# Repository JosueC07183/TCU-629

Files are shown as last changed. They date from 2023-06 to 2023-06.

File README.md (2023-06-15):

# TCU-629 Dispensador de alcohol en gel

Como parte de requisito de graduación los estudiantes de la Universidad de Costa Rica deben realizar un trabajo comunal universitario, comúnmente abreviado como TCU. En esta ocasión, un grupo de estudiantes de varias carreras tomaron la decisión de construir un dispensador de alcohol en gel automático desde 0, es decir, pensaron en un diseño que se adaptará a los materiales que contaba el laboratorio de industrial, por lo que fue un gran reto debido a que se tuvo invertir mucho tiempo en el diseño de las piezas, ya que era necesario que éstas tuvieran el mayor detalle posible, donde muchas ocasiones el material de trabajo no se adaptaba a lo solicitado, pero gracias al desempeño, perseverancia y voluntad del equipo de trabajo en ayudar al Hogar de ancianos San Pedro  Claver fue posible crear el dispensador, que se sometió a período de prueba cumpliendo satisfactoriamente su trabajo.

--- 
# Creación del primer prototipo
- Al cabo de 3 meses de mucho trabajo por sesiones diarias durante el período de verano de 2022-2023, el equipo de trabajo logró construir el primer dispensador, o la prueba de concepto.

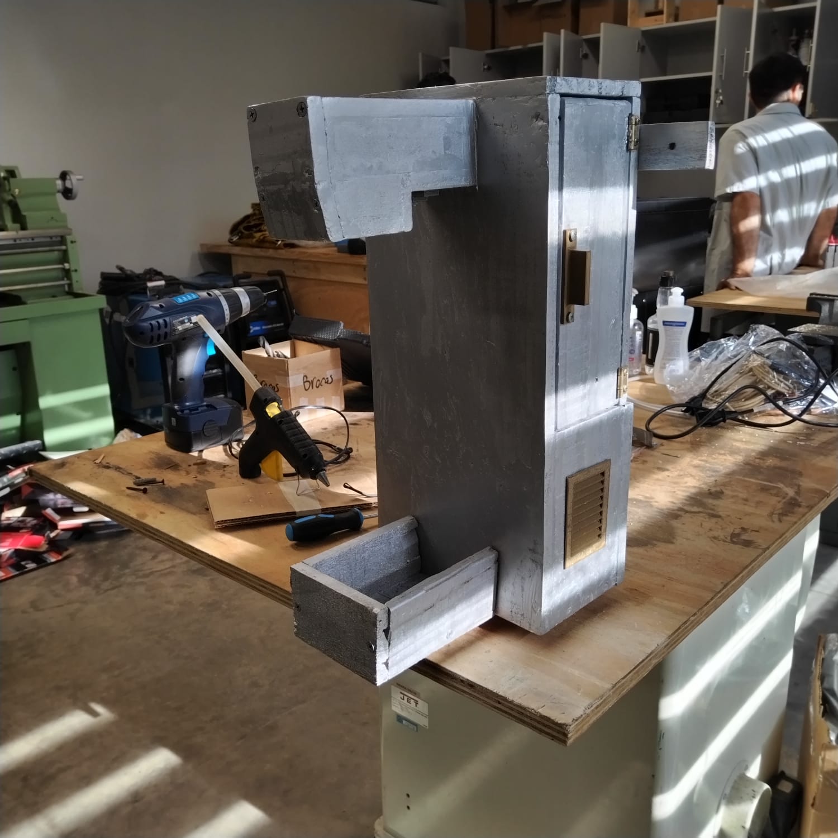
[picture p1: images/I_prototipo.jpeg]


**Nota**
> El dispensador mostrado en la imagen de arriba fue creado con los materiales disponibles en el laboratorio, que gracias a la creatividad del equipo de trabajo fue posible su construcción.

---
# Entrega del primer prototipo
- Una vez se completó el dispensador, se procedió a entregarlo al hogar de ancianos San Pedro Claver el día 20 de abril.

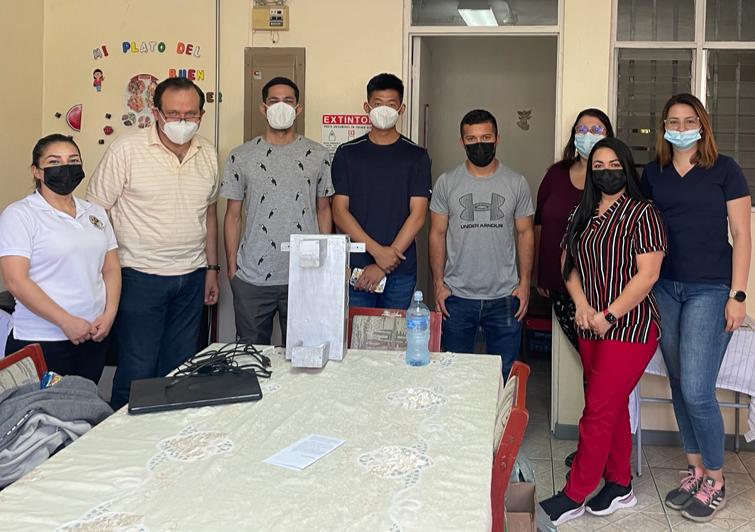
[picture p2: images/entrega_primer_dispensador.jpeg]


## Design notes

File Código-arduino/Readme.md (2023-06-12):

## En esta carpeta encontrará el código que le da vida a la estructura de nuestro dispensador.
---
- En el archivo .ino se muestra la documentación del código.

```
const int rele = 2;
int trig = 12;
int echo = 11;
float distancia;
long duracion;
int pot;
int cantidad;
int led_rojo = 5;
int led_verde= 6;
const int buzzer = 9;

void setup() {
  Serial.begin(9600);
  pinMode(rele , OUTPUT);
  pinMode(trig, OUTPUT);
  pinMode(echo, INPUT);
  pinMode(led_rojo, OUTPUT); 
  pinMode(led_verde, OUTPUT);
  pinMode(buzzer, OUTPUT);   
}
 
void loop(){

    pot = analogRead(A0);
    cantidad = pot/10.23;
    Serial.print("Cantidad es de = ");
    Serial.println(cantidad);

    digitalWrite(trig, LOW);
    delayMicroseconds(2);
    digitalWrite(trig, HIGH);
    delayMicroseconds(10);
    digitalWrite(trig, LOW);
    duracion = pulseIn(echo, HIGH);
    distancia = duracion/57.8;
    Serial.print(distancia);
    Serial.println("cm");

    digitalWrite(led_rojo, LOW);
    digitalWrite(led_verde, HIGH);
    
    //Código para el accionar de la bomba
    if(distancia <=12 && distancia>7){ 
    delay(500) ; 
    digitalWrite(rele, HIGH);
    digitalWrite(led_verde, LOW);
    digitalWrite(led_rojo, HIGH); 
    delay(cantidad);
    digitalWrite(rele, LOW);
    
    analogWrite (buzzer,5000); 
    delay(3000); 
    analogWrite (buzzer,0);
  	}

    //delay(100); // este delay es para reducir la cantidad de lecturas seguidas del sensor
  }  ```

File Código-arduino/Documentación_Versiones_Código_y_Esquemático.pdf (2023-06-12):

Universidad de Costa Rica

Escuela de Ingeniería Industrial
TCU-629 Dispensador Automatico, 2023 ´

# Documentación de Código y Esquema Electrónico

## Documentación de trabajo

### TCU-629-Ver1.0

Resumen

El presente documento muestra la documentación relacionada al circuito electrónico diseñado para el funcionamiento del dispensador, en este documento se presenta tanto el diagrama electrónico como la programación en Arduino para distintas propuestas que se han planteado implementar a lo largo del proceso de diseño del dispensador hasta la fecha, así como se indican las razones por las cuales algunas de las propuestas no fueron implementadas finalmente en el dispensador. También, se muestra la documentación relacionada a las versiones del circuito que si han sido implementadas en algún momento, así como la versión más reciente con la que se encuentra el dispensador funcionando.

### Fecha | Marzo, 2023 Autor 1 | Jose Pablo Valverde Brandford Profesor Coordinador | Michael Fernández Vega

1

TCU-629-Ver1.0 | Documentación de trabajo

# Índice

1. Versiones Propuestas. | 3

### 1.2. Versión con buzzer indicador de nivel de alcohol y LED indicador de accio-

2. Versión sin potenciómetro (06/01/2023). | 15
3. Versión Primer modelo (02/02/2023). | 17
4. Versión actual, segundo modelo (23/05/2023). | 20

2

TCU-629-Ver1.0 | Documentación de trabajo
1. Versiones Propuestas.
1.1. Versión con buzzer indicador de nivel de alcohol.

### Esta versión fue propuesta por el Autor 1, consiste en la implementación de un sistema

para controlar el nivel de alcohol en gel en el recipiente de almacenamiento, por medio de un sensor ultrasónico colocado en la boca del recipiente se mide la distancia desde la boca del recipiente a la capa superior del alcohol dentro del recipiente, en el momento en que el sensor mida una distancia definida como el fondo de la botella entonces el buzzer activa una alarma que indica que el recipiente se encuentra vacío.

### A continuación se enumeran las razones por las que no fue implementada esta versión:

### Dificultad para colocar el sensor en la boca de la botella y que a la vez se deje espacio

para realizar el llenado de la misma.

### Posibilidad de que la vida útil del sensor en la botella se reduzca debido a la humedad o al constante manejo y movimiento al que estaría expuesto debido a que por el diseño

del dispensador la botella debe sacarse del mismo para rellenarla.

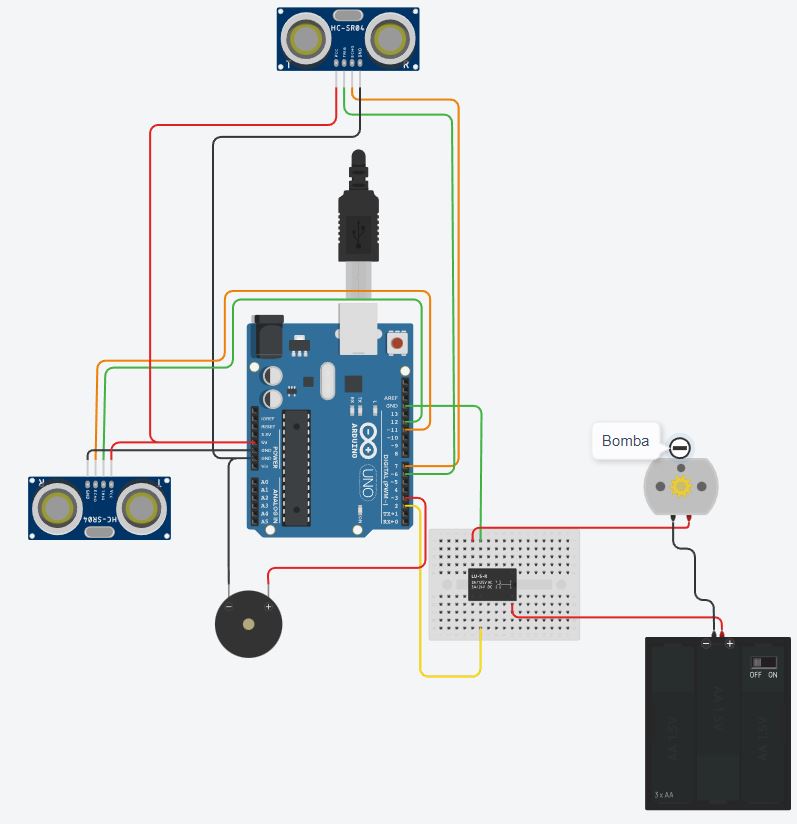
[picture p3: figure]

Figura 1: Captura del circuito con buzzer indicador de nivel de alcohol.

3

TCU-629-Ver1.0 | Documentación de trabajo

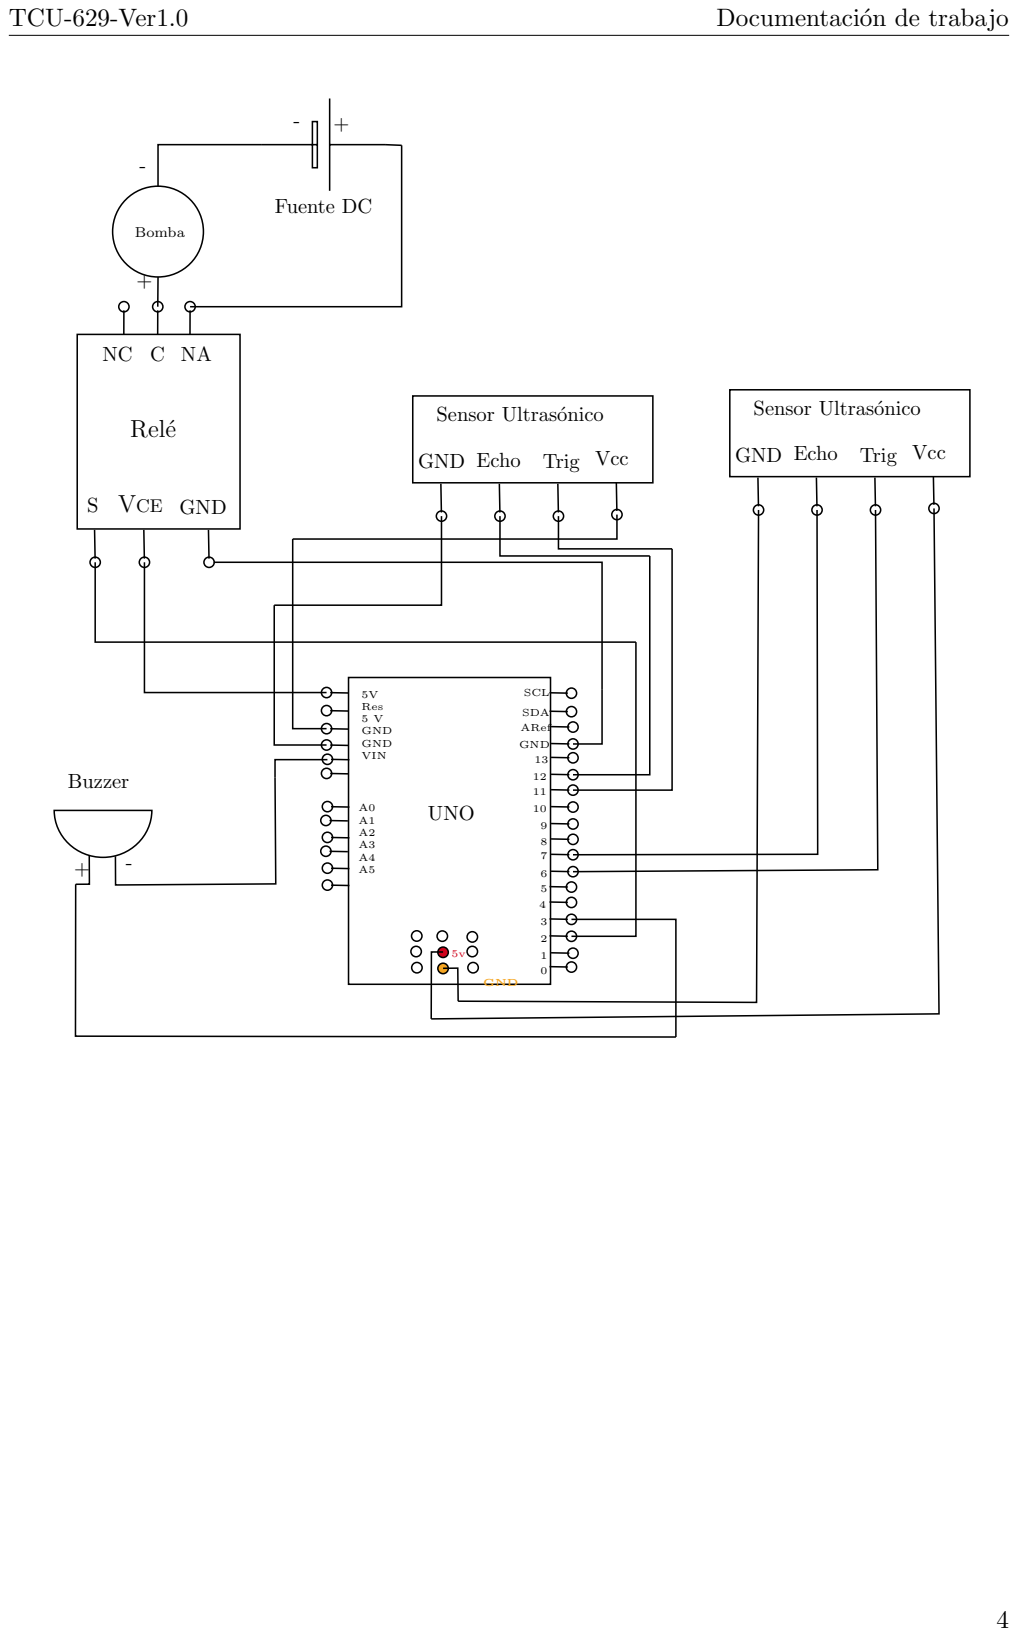
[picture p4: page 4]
UNO; 5V Res 5 V GND GND VIN; SCL; Bomba; S VCE GND; Relé; Fuente DC; GND Echo; Trig; Vcc; SDA; ARef; GND; Buzzer

Sensor Ultrasónico

TCU-629-Ver1.0 | Documentación de trabajo

1

2
3 #i n cl u d e <Wire . h>

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

12

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

19
20 v oid se tup ( ) {

21

22
23 | S e r ia l . b e gi n ( 9600 ) ; | // i n i c i a r pue r t o s e r i e
24 | pinMode (Bomba , OUTPUT) ; | // d e f i n i r pin como s a l i d a
25 | pinMode ( t r i g , OUTPUT) ;
26 | pinMode ( echo , INPUT PULLUP) ;

27
28 | pinMode ( t r i g 2 ,OUTPUT) ;
29 | pinMode ( echo 2 ,INPUT PULLUP) ;

30
31 pinMode ( buzzer ,OUTPUT) ;

32

33
34 }

35
36 v oid l o o p ( ) {

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

51

52
53 | }

54
55 //−+−+−+−+−+−+−+−+−+−+−+−+−+−+−+−+−+−+ Sen s o r mano y bomba +−+−+−+−+−+−+−+−+

5

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

65
66 i f ( d i s t a n c i a <=100 ) {

67
68 | d i g i t a lW r i t e (Bomba, HIGH) ;
69 | d el a y ( 1000 ) ; // Tiempo que dura l a bomba encendid a
70 | d i g i t a lW r i t e (Bomba, LOW) ;
71 | d el a y ( 5000 ) ;
72 | }
73 | e l s e {
74 | d i g i t a lW r i t e (Bomba, LOW) ;
75 | }

76
77 | d el a y ( 500 ) ;
78 | }

### Listing 1: Código de programación del circuito anterior

6

TCU-629-Ver1.0 | Documentación de trabajo

## 1.2. Versión con buzzer indicador de nivel de alcohol y LED indi-

cador de accionamiento de bomba.

Esta versión fue propuesta por el Autor 1, consiste en la implementación del mismo sistema para controlar el nivel de alcohol en gel en el recipiente de almacenamiento mencionado

### en la versión anterior pero ahora implementando también un diodo LED el cual indica el accionamiento de la bomba. La finalidad de la implementación del diodo LED es que en

caso de que el dispensador presente algún problema se pueda identificar rápidamente si el

### sistema de la bomba está alimentado y funcionando bien y descartar que el problema que

presente el dispensador sea propiciado por un fallo en las conexiones de l bomba o el sensor. En otras palabras, el LED sería un indicador de que el sistema electrónico del dispensador se encuentra funcionando correctamente.

### A continuación se enumeran las razones por las que no fue implementada esta versión:

### Dificultad para colocar el sensor en la boca de la botella y que a la vez se deje espacio

para realizar el llenado de la misma.

### Posibilidad de que la vida útil del sensor en la botella se reduzca debido a la humedad o al constante manejo y movimiento al que estaría expuesto debido a que por el diseño

del dispensador la botella debe sacarse del mismo para rellenarla.

### Se considera innecesario la implementación del LED ya que la bomba produce un sonido suficientemente alto como para que ese sonido pueda ser indicador de que el

sistema electrónico se encuentra funcionando correctamente.

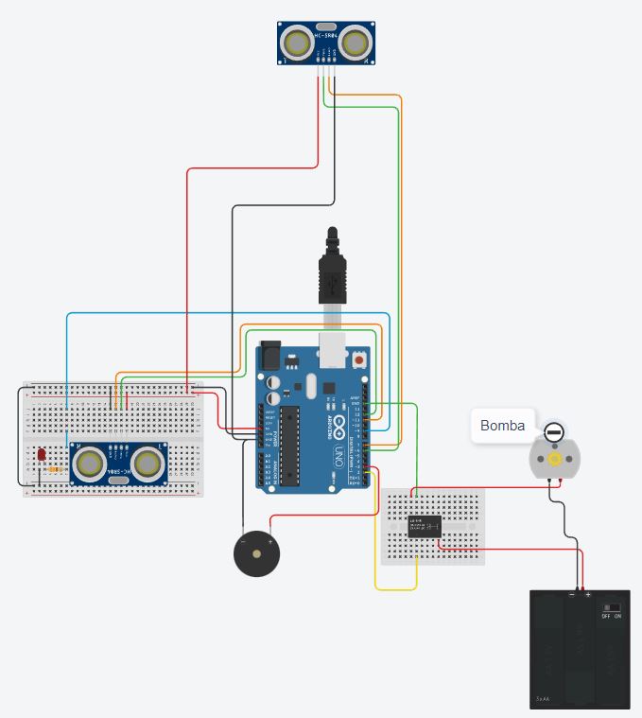
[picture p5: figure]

Figura 2: Captura del circuito con buzzer indicador de nivel de alcohol y LED indicador de accionamiento del dispensador.

7

TCU-629-Ver1.0 | Documentación de trabajo

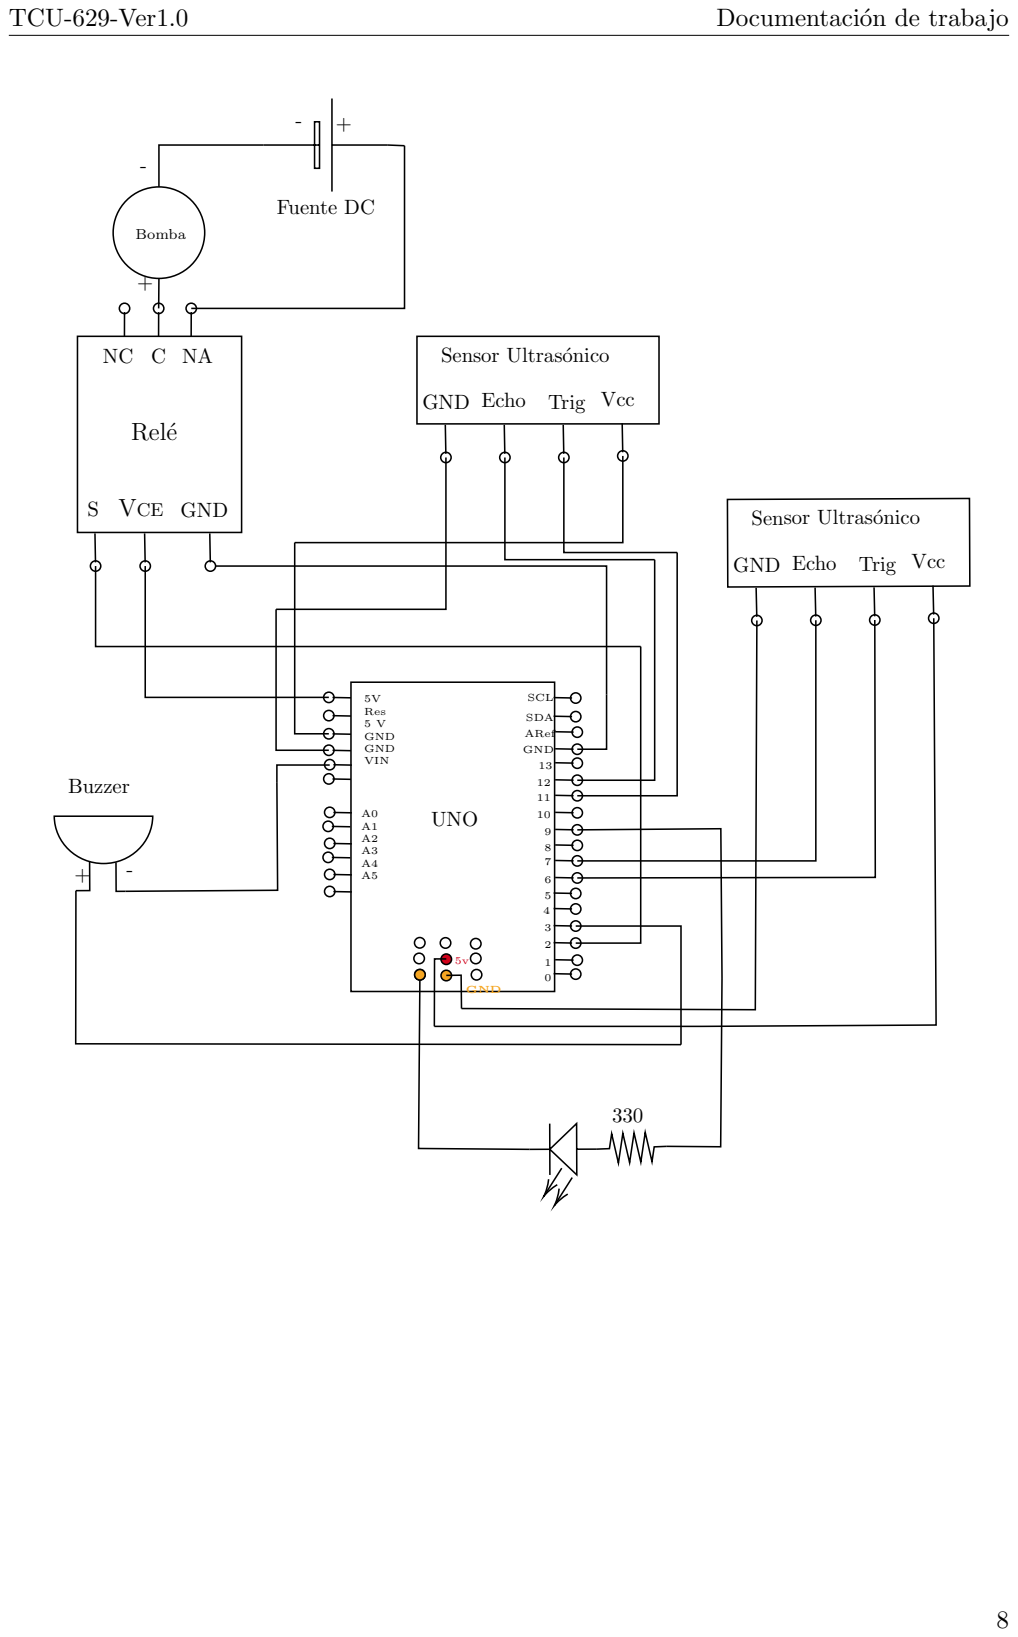
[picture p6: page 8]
UNO; 5V Res 5 V GND GND VIN; SCL; Bomba; S VCE GND; Relé; Fuente DC; GND Echo; Trig; Vcc; SDA; ARef; GND; Buzzer

Sensor Ultrasónico

TCU-629-Ver1.0 | Documentación de trabajo

1

2
3 #i n cl u d e <Wire . h>

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

19

20
21 v oid se tup ( ) {

22

23
24 | S e r ia l . b e gi n ( 9600 ) ; | // i n i c i a r pue r t o s e r i e
25 | pinMode (Bomba , OUTPUT) ; | // d e f i n i r pin como s a l i d a
26 | pinMode ( t r i g , OUTPUT) ;
27 | pinMode ( echo , INPUT PULLUP) ;
28 | pinMode (LED Bomba, OUTPUT) ;

29
30 | pinMode ( t r i g 2 ,OUTPUT) ;
31 | pinMode ( echo 2 ,INPUT PULLUP) ;

32
33 pinMode ( buzzer ,OUTPUT) ;

34

35
36 }

37
38 v oid l o o p ( ) {

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

53

54
55 | }

56

9

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

67
68 i f ( d i s t a n c i a <=100 ) {

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

80
81 | d el a y ( 500 ) ;
82 | }

### Listing 2: Código de programación del circuito anterior

10

TCU-629-Ver1.0 | Documentación de trabajo
1.3. Versión con Indicador de LEDs para nivel de alcohol.

### Esta versión fue propuesta por el Autor 1, consiste en la implementación de un sistema para controlar el nivel de alcohol en gel en el recipiente de almacenamiento por medio de

un indicador de tres niveles con LEDs, este sistema utiliza de igual forma que las versiones propuestas anteriores, un sensor ultrasónico para medir el nivel de alcohol en la botella,

### conforme el sensor colocado en la boca de la botella va midiendo una distancia mayor, el sistema indicador con LEDs va cambiando el LED alimentado, cuando la distancia medida

es pequeña, significa que la botella se encuentra relativamente llena, entonces el LED que se

### encuentra prendido es el verde, cuando la botella se encuentra en un rango medio entonces

el LED es amarillo, y cuando la botella se encuentra vacía entonces se prende el LED rojo.

### A continuación se enumeran las razones por las que no fue implementada esta versión:

### Dificultad para colocar el sensor en la boca de la botella y que a la vez se deje espacio

para realizar el llenado de la misma.

### Posibilidad de que la vida útil del sensor en la botella se reduzca debido a la humedad o al constante manejo y movimiento al que estaría expuesto debido a que por el diseño

del dispensador la botella debe sacarse del mismo para rellenarla.

### Se tendría que implementar el uso de una protoboard lo que implicaría un mayor

espacio dentro del dispensador para el circuito electrónico.

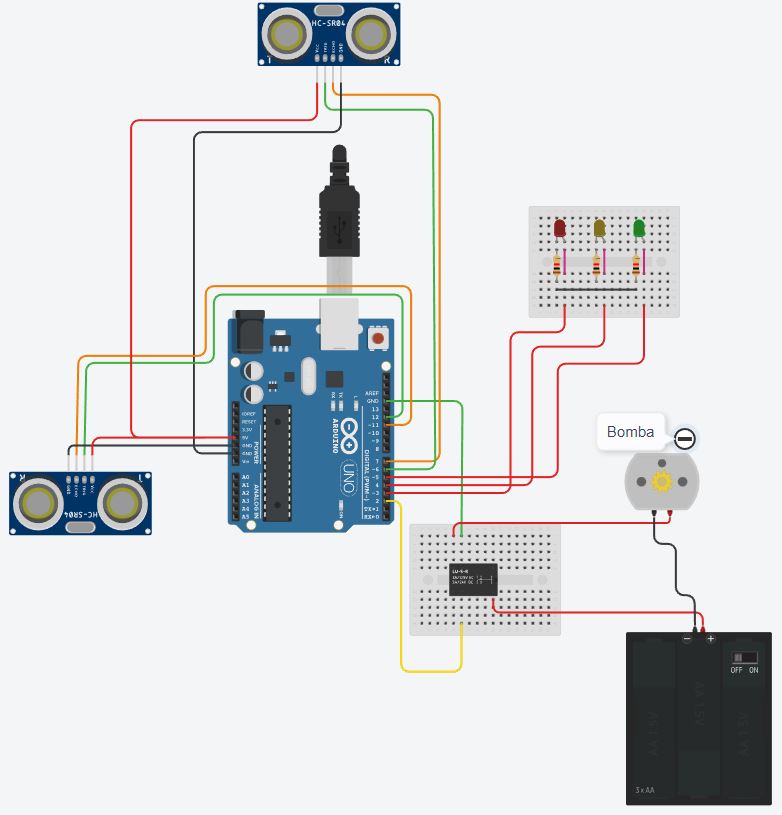
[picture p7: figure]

Figura 3: Captura del circuito con circuito de LEDs indicador de nivel de alcohol.

11

TCU-629-Ver1.0 | Documentación de trabajo

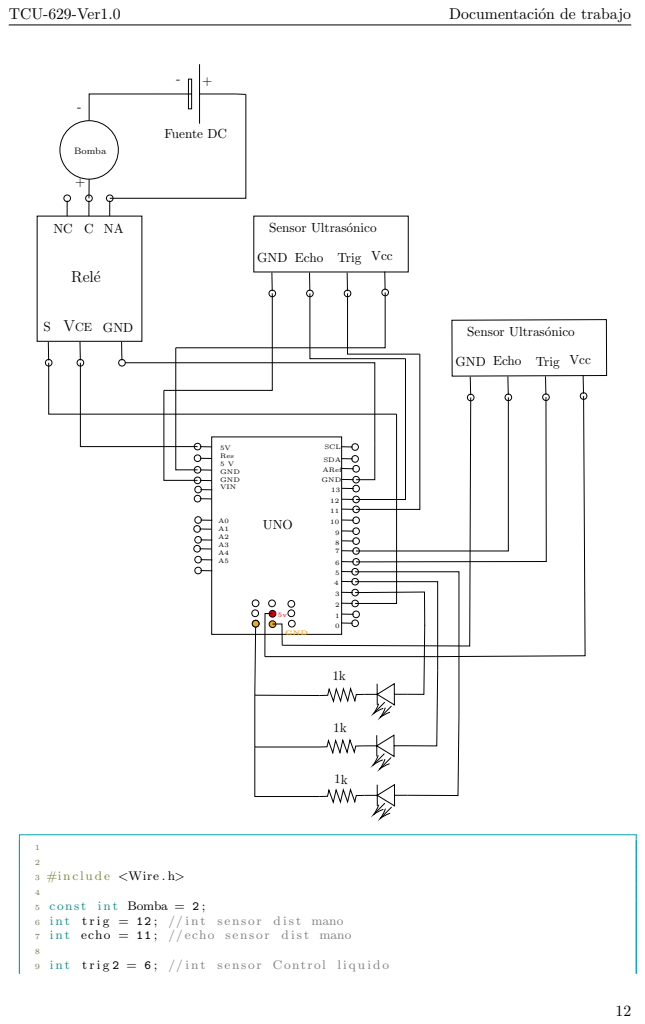
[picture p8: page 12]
UNO; 5V Res 5 V GND GND VIN; SCL; Bomba; S VCE GND; Relé; Fuente DC; GND Echo; Trig; Vcc; SDA; ARef; GND; 2 3 #i n cl u d e <Wire . h>; c o n s t i n t Bomba = 2 ;; i n t t r i g = 12 ; // i n t s e n s o r d i s t mano; i n t echo = 11 ; // echo s e n s o r d i s t mano

Sensor Ultrasónico

TCU-629-Ver1.0 | Documentación de trabajo
10 | i n t echo 2 = 7 ; // echo s e n s o r C on t r ol l i q u i d o

11

12

13

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

17
18 | i n t LED Ro jo Ind Nivel = 3 ;
19 | i n t LED Am a rill o Ind Ni vel = 4 ;
20 | i n t LED Verde Ind Nivel = 5 ;

21

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

25

26
27 v oid se tup ( ) {

28

29
30 | S e r ia l . b e gi n ( 9600 ) ; | // i n i c i a r pue r t o s e r i e
31 | pinMode (Bomba , OUTPUT) ; | // d e f i n i r pin como s a l i d a
32 | pinMode ( t r i g , OUTPUT) ;
33 | pinMode ( echo , INPUT PULLUP) ;

34

35
36 | pinMode ( t r i g 2 ,OUTPUT) ;
37 | pinMode ( echo 2 ,INPUT PULLUP) ;

38
39 | pinMode ( LED Ro jo Ind Nivel ,OUTPUT) ;
40 | pinMode ( LED Am a rill o Ind Nivel ,OUTPUT) ;
41 | pinMode ( LED Verde Ind Nivel ,OUTPUT) ;

42

43
44 }

45
46 v oid l o o p ( ) {

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

49

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

60
61 | d i g i t a lW r i t e ( LED Ro jo Ind Nivel ,HIGH) ;
62 | d i g i t a lW r i t e ( LED Am a rill o Ind Nivel ,LOW) ;
63 | d i g i t a lW r i t e ( LED Verde Ind Nivel ,LOW) ;

64

13

TCU-629-Ver1.0 | Documentación de trabajo
65 | }
66 | i f | ( Nivel<250 && Nivel>=100 ) {

67
68 | | d i g i t a lW r i t e ( LED Ro jo Ind Nivel ,LOW) ;
69 | | d i g i t a lW r i t e ( LED Am a rill o Ind Nivel ,HIGH) ;
70 | | d i g i t a lW r i t e ( LED Verde Ind Nivel ,LOW) ;

71
72 | }
73 | i f | ( Nivel<100 ) {

74
75 | | d i g i t a lW r i t e ( LED Ro jo Ind Nivel ,LOW) ;
76 | | d i g i t a lW r i t e ( LED Am a rill o Ind Nivel ,LOW) ;
77 | | d i g i t a lW r i t e ( LED Verde Ind Nivel ,HIGH) ;

78
79 | }

80

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

92
93 i f ( d i s t a n c i a <=100 ) {

94
95 | | d i g i t a lW r i t e (Bomba, HIGH) ;
96 | | d el a y ( 1000 ) ; // Tiempo que dura l a bomba encendid a
97 | | d i g i t a lW r i t e (Bomba, LOW) ;
98 | | d el a y ( 5000 ) ;
99 | }
100 | e l s e {
101 | d i g i t a lW r i t e (Bomba, LOW) ;
102 | }

103
104 | d el a y ( 500 ) ;
105 | }

### Listing 3: Código de programación del circuito anterior

14

TCU-629-Ver1.0 | Documentación de trabajo
2. Versión sin potenciómetro (06/01/2023).

Esta versión es la más básica para el funcionamiento del dispensador, fue propuesta por los compañeros que empezaron el diseño de este proyecto en semestres anteriores, consiste

únicamente en un sensor ultrasónico colocado en la boquilla del dispensador que detecta cuando se acerca la mano, luego es accionada la bomba de diafragma que toma el alcohol del dispensador presente dentro de la carcasa del dispensador y lo dispensa por medio de la boquilla a la mano del usuario, todo controlado por el módulo de Arduino UNO. Esta

versión fue implementada y probada con éxito en el dispensador.

15

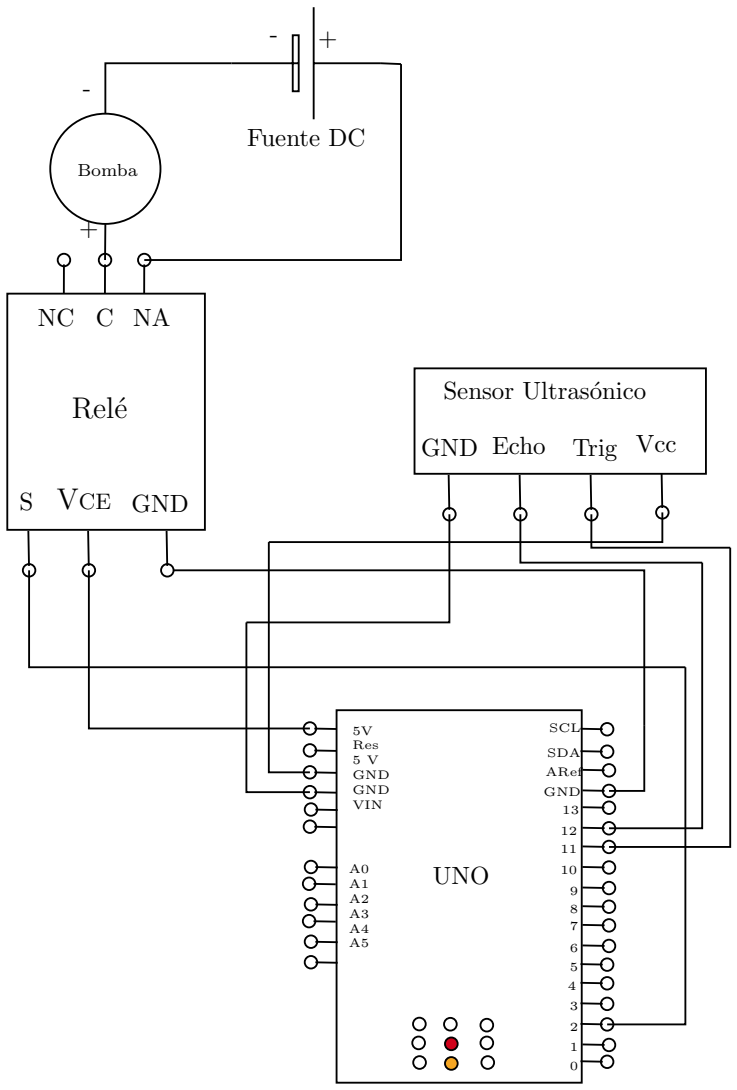
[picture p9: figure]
UNO; 5V Res 5 V GND GND VIN; SCL; Bomba; S VCE GND; Relé; Fuente DC; GND Echo; Trig; Sensor Ultrasónico; Vcc; SDA; ARef; GND

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

7
8 | v oid se tup ( ) {
9 | S e r ia l . b e gi n ( 9600 ) ; | // i n i c i a r pue r t o s e r i e
10 | pinMode ( r e l e , OUTPUT) ; | // d e f i n i r pin como s a l i d a
11 | pinMode ( t r i g , OUTPUT) ; | // t r i g s a l i d a
12 | pinMode ( echo , INPUT) ; // echo en t r ad a
13 | }

14
15 v oid l o o p ( ) {

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

39 }

### Listing 4: Código de programación del circuito anterior

16

TCU-629-Ver1.0 | Documentación de trabajo
3. Versión Primer modelo (02/02/2023).

### Esta versión se basa en la anterior, es en esencia exactamente igual electrónicamen-te hablando pero ahora por recomendación del profesor coordinado Michael Fernández se implementa un potenciómetro que permite regular la cantidad de alcohol que dispensa el

dispositivo diseñado. Esta versión fue implementada y probada con éxito en el dispensador y a la fecha de la última actualización del presente documento, esta es la versión con la que se encuentra funcionando el dispositivo.

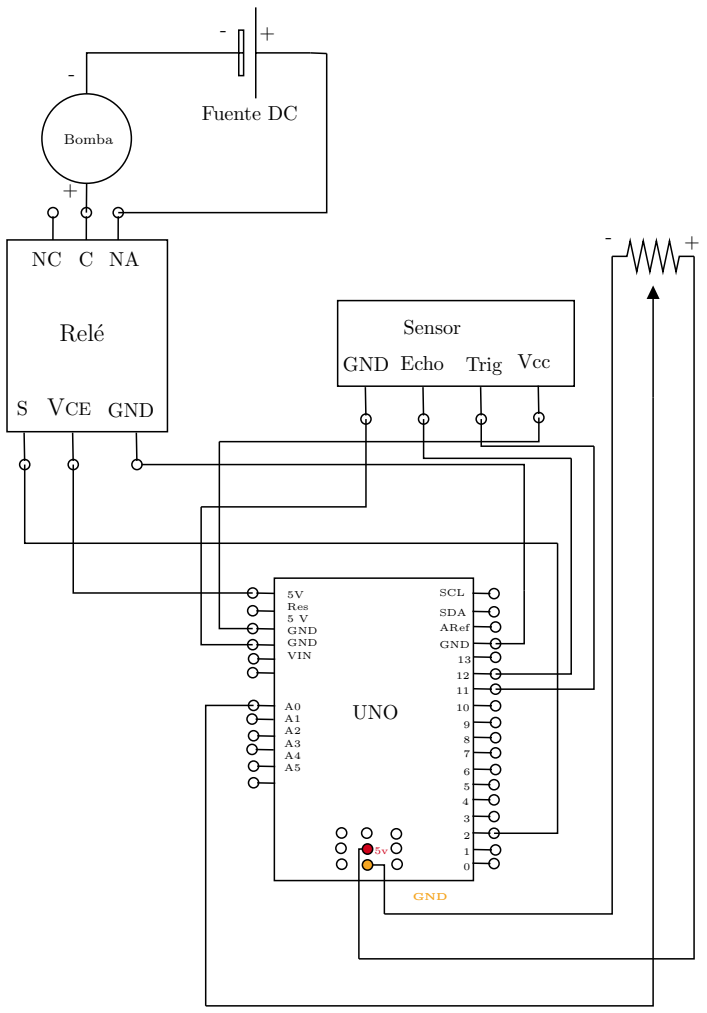
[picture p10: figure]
UNO; 5V Res 5 V GND GND VIN; SCL; Bomba; S VCE GND; Relé; Fuente DC; GND; GND Echo; Trig; Sensor; Vcc; SDA; ARef

Figura 4: Esquemático eléctrico dispensador de alcohol.

17

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

9

10
11 | v oid se tup ( ) {
12 | S e r ia l . b e gi n ( 9600 ) ; | // i n i c i a r pue r t o s e r i e
13 | pinMode ( r e l e , OUTPUT) ; | // d e f i n i r pin como s a l i d a
14 | pinMode ( t r i g , OUTPUT) ; // t r i g s a l i d a
15 | pinMode ( echo , INPUT) ; // echo en t r ad a
16 | }

17
18 v oid l o o p ( ) {

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

36

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

18

TCU-629-Ver1.0 | Documentación de trabajo

### Listing 5: Código de programación del pimer modelo

19

TCU-629-Ver1.0 | Documentación de trabajo
4. Versión actual, segundo modelo (23/05/2023).

### A partir de la retroalimentación obtenida a partir del personal del hogar de ancianos

luego del periodo de pruebas del primer modelo del dispensador, se evalúan varias opciones

### de mejora, escogiendo la opción de implementar un sistema indicador de LEDs y buzzer

con el fin de que sirva como señal al usuario para que éste sepa cuando el dispensador se encuentra listo para dispensar el alcohol, y cuando el dispositivo se encuentra realizando el

### delay entre accionamiento, esto permite evitar que el usuario ponga la mano muy seguido y

al dispensador no le dé tiempo de dispensar el alcohol.

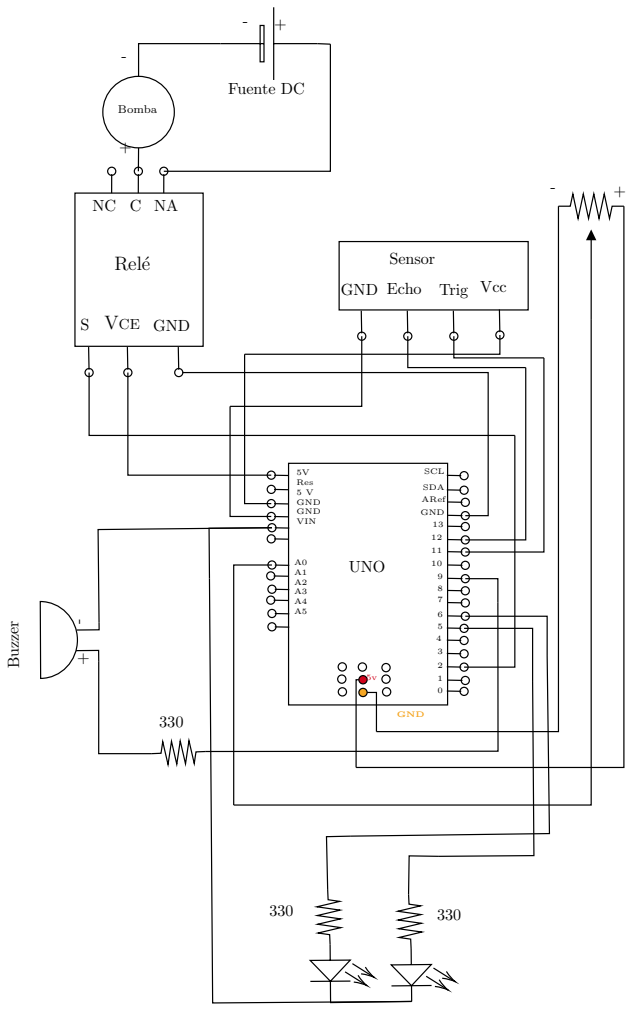
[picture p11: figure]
UNO; 5V Res 5 V GND GND VIN; SCL; Bomba; S VCE GND; Relé; Fuente DC; GND; GND Echo; Trig; Sensor; Vcc; SDA; ARef; Buzzer

Figura 5: Esquemático eléctrico dispensador de alcohol.

20

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

12
13 | v oid se tup ( ) {
14 | S e r ia l . b e gi n ( 9600 ) ; | // i n i c i a r pue r t o s e r i e
15 | pinMode ( r e l e , OUTPUT) ; | // d e f i n i r pin como s a l i d a
16 | pinMode ( t r i g , OUTPUT) ; // t r i g s a l i d a
17 | pinMode ( echo , INPUT) ; // echo en t r ad a
18 | pinMode ( l e d r o j o , OUTPUT) ;
19 | pinMode ( l e d v e r d e , OUTPUT) ;
20 | pinMode ( buzzer , OUTPUT) ;
21 | }

22
23 v oid l o o p ( ) {

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

21

TCU-629-Ver1.0 | Documentación de trabajo

53
54 | an al o gW ri te ( buzzer , 5000 ) ;
55 | d el a y ( 3000 ) ; // demora para que vuel v a a f u n ci o n a r l a bomba en c a s o
| de u t i l i z a r s e s e g ui d o
56 | an al o gW ri te ( buzzer , 0 ) ;
57 | }

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

### Listing 6: Código de programación más reciente a la fecha

22

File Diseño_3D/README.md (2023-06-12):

## En esta carpeta se encontrará el archivo del diseño 3D del dispensador de alcohol.

---

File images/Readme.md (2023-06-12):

# Evidencias de trabajo
---
- En esta carpeta contiene las imágenes de los momentos más importantes del proyecto.

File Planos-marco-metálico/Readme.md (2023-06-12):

# Dimensiones del marco metálico
---
> Aquí encontrará un archivo pdf que contiene las dimensiones del esqueleto del dispositivo, las podrá consultar para conocer con más detalles del trabajo.

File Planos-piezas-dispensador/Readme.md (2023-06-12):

# Dimensiones y enumeraciones de las piezas
---
> En este archivo pdf podrá consultar el armado del dispensador, ubicación de las piezas, cortes y dimensiones.

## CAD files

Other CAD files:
Planos-piezas-dispensador/Planos segundo modelo.dwg
Diseño_3D/Piezas Impresión 3D/Base Sensor Hueco 2.0 v6 v7 v2.f3d
Diseño_3D/Piezas Impresión 3D/BoquillaConica v2.f3d
Diseño_3D/Piezas Impresión 3D/Manilla v2.f3d
Diseño_3D/Piezas Impresión 3D/Rejilla v3 v2.f3d
Diseño_3D/Piezas Impresión 3D/Soporte Manguera v4 v2.f3d
Diseño_3D/Piezas Impresión 3D/Soporte_Poten v4.f3d
Diseño_3D/Piezas Impresión 3D/bocaadaptador v4 v1.f3d

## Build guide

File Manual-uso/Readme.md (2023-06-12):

# Manual de uso
> Aquí podrá encontrar un archivo (a modo de resumen) del uso del dispositivo.

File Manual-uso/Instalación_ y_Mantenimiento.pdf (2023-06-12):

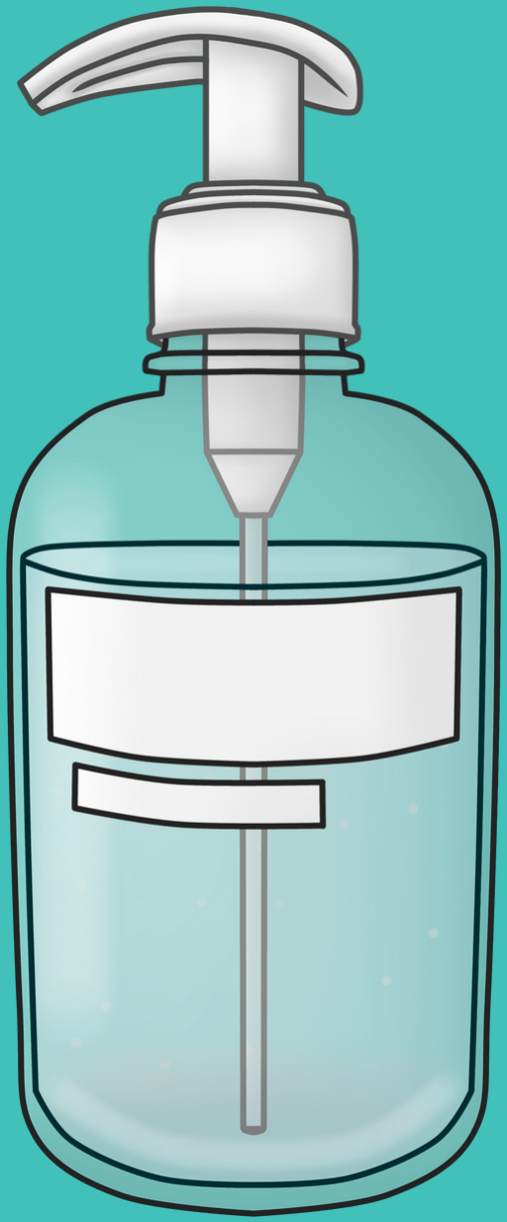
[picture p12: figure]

# INSTALACION Y MANTNIMIENTO DEL DISPENSADOR DE ALCOHOL

# Instrucciones Para

## TCU-629-G08

# Instrucciones de Instalacion

# Diagrama de flujo de Instalacion

# Instrucciones de Mantenimiento

# Diagrama de Flujo de Mantenimiento

01

02

03

04

# CONTENIDOS

# INSTALACION DEL DISPENSADOR

Definir un lugar seguro cerca de alguna fuente de alimentacion, para colocar el dispensador.

01

Realice los agujeros nesesarios en la 02 pared donde se ubica el dispositivo.

Con la ayuda de tacos tarugos de 1/8 sujete el dispositvo a la pared y conecte a la fuente de alimentacion.

03

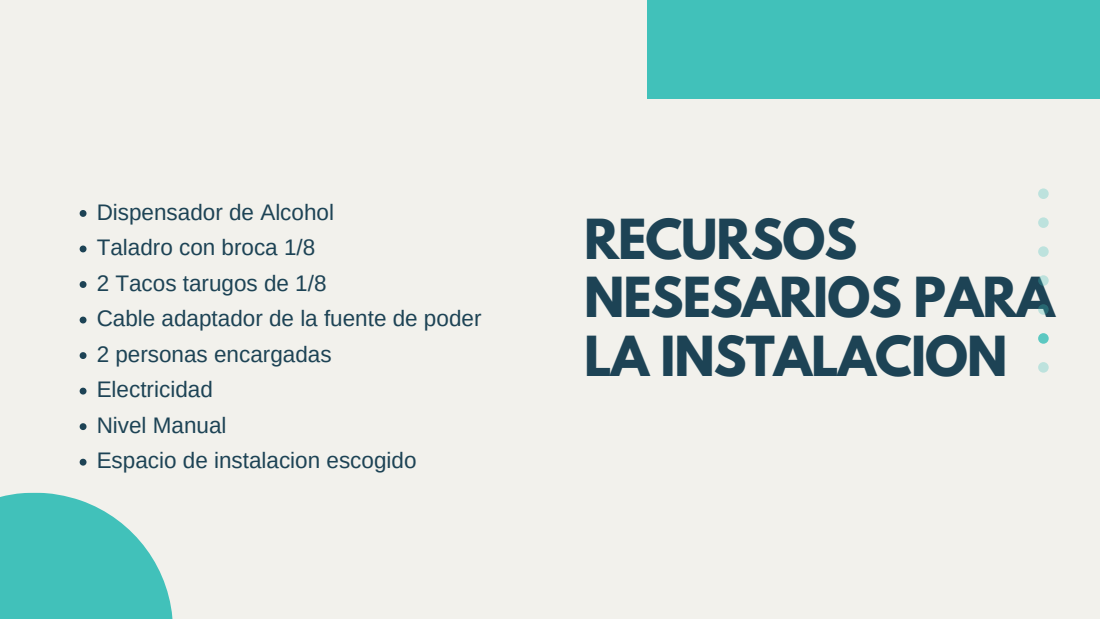
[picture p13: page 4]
RECURSOS NESESARIOS PARA LA INSTALACION

Dispensador de Alcohol
Taladro con broca 1/8
2 Tacos tarugos de 1/8
Cable adaptador de la fuente de poder
2 personas encargadas
Electricidad
Nivel Manual
Espacio de instalacion escogido

# DIAGRAMA DE FLUJO INSTALACION

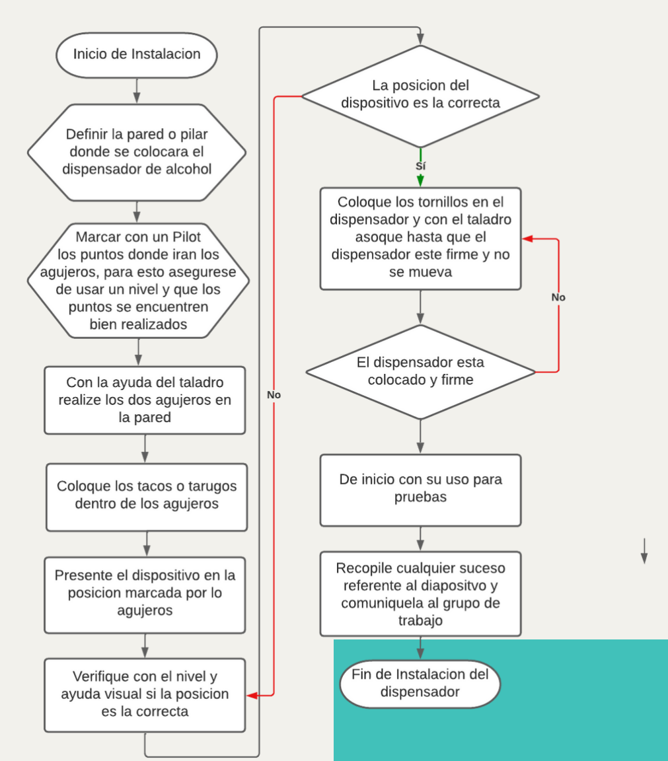
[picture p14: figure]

Se realiza mantenimiento cada vez que se agote el alchol en gel del dispensador, para ello desconecte el mismo.

01

Al prototipo tener su propia botella esta debe ser retirada, con cuidado de no dañar la manguera de dispensado.

02

Rellene la misma botella e introdusca de nuevo en el
dispositvo, coloque la tapa y cierre el dispensador.

03

# MANTENIMIENTO DEL DISPENSADOR

# RECURSOS DE MANTENIEMTO

## Alcohol en gel 500 ml Botella del dispensador tapa de la botella 1 persona encargada

# DIAGRAMA DE FLUJO DE MANTENIMIENTO

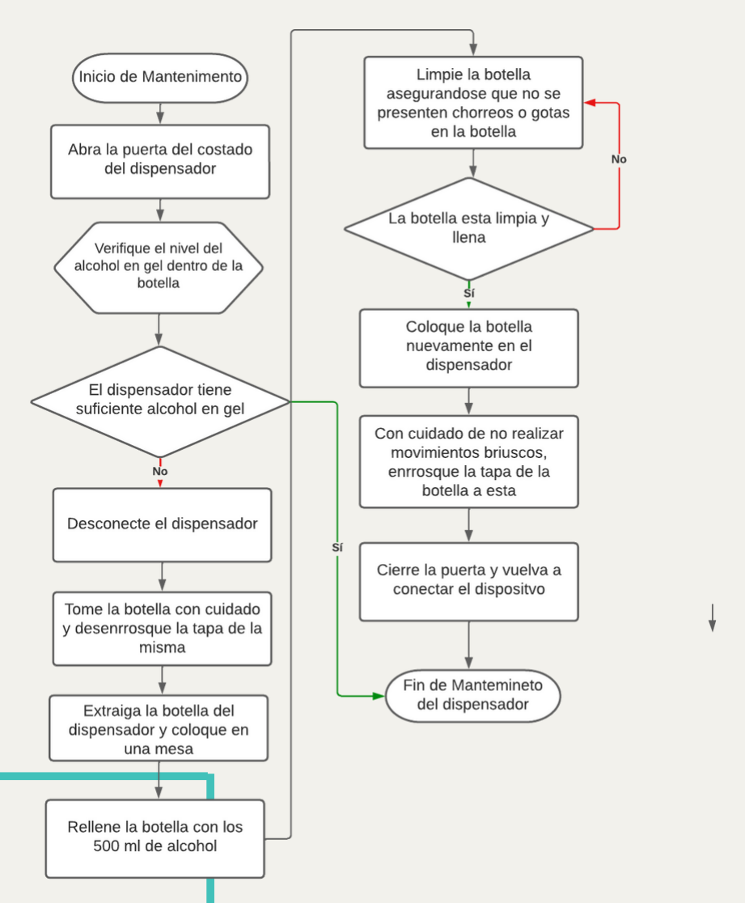
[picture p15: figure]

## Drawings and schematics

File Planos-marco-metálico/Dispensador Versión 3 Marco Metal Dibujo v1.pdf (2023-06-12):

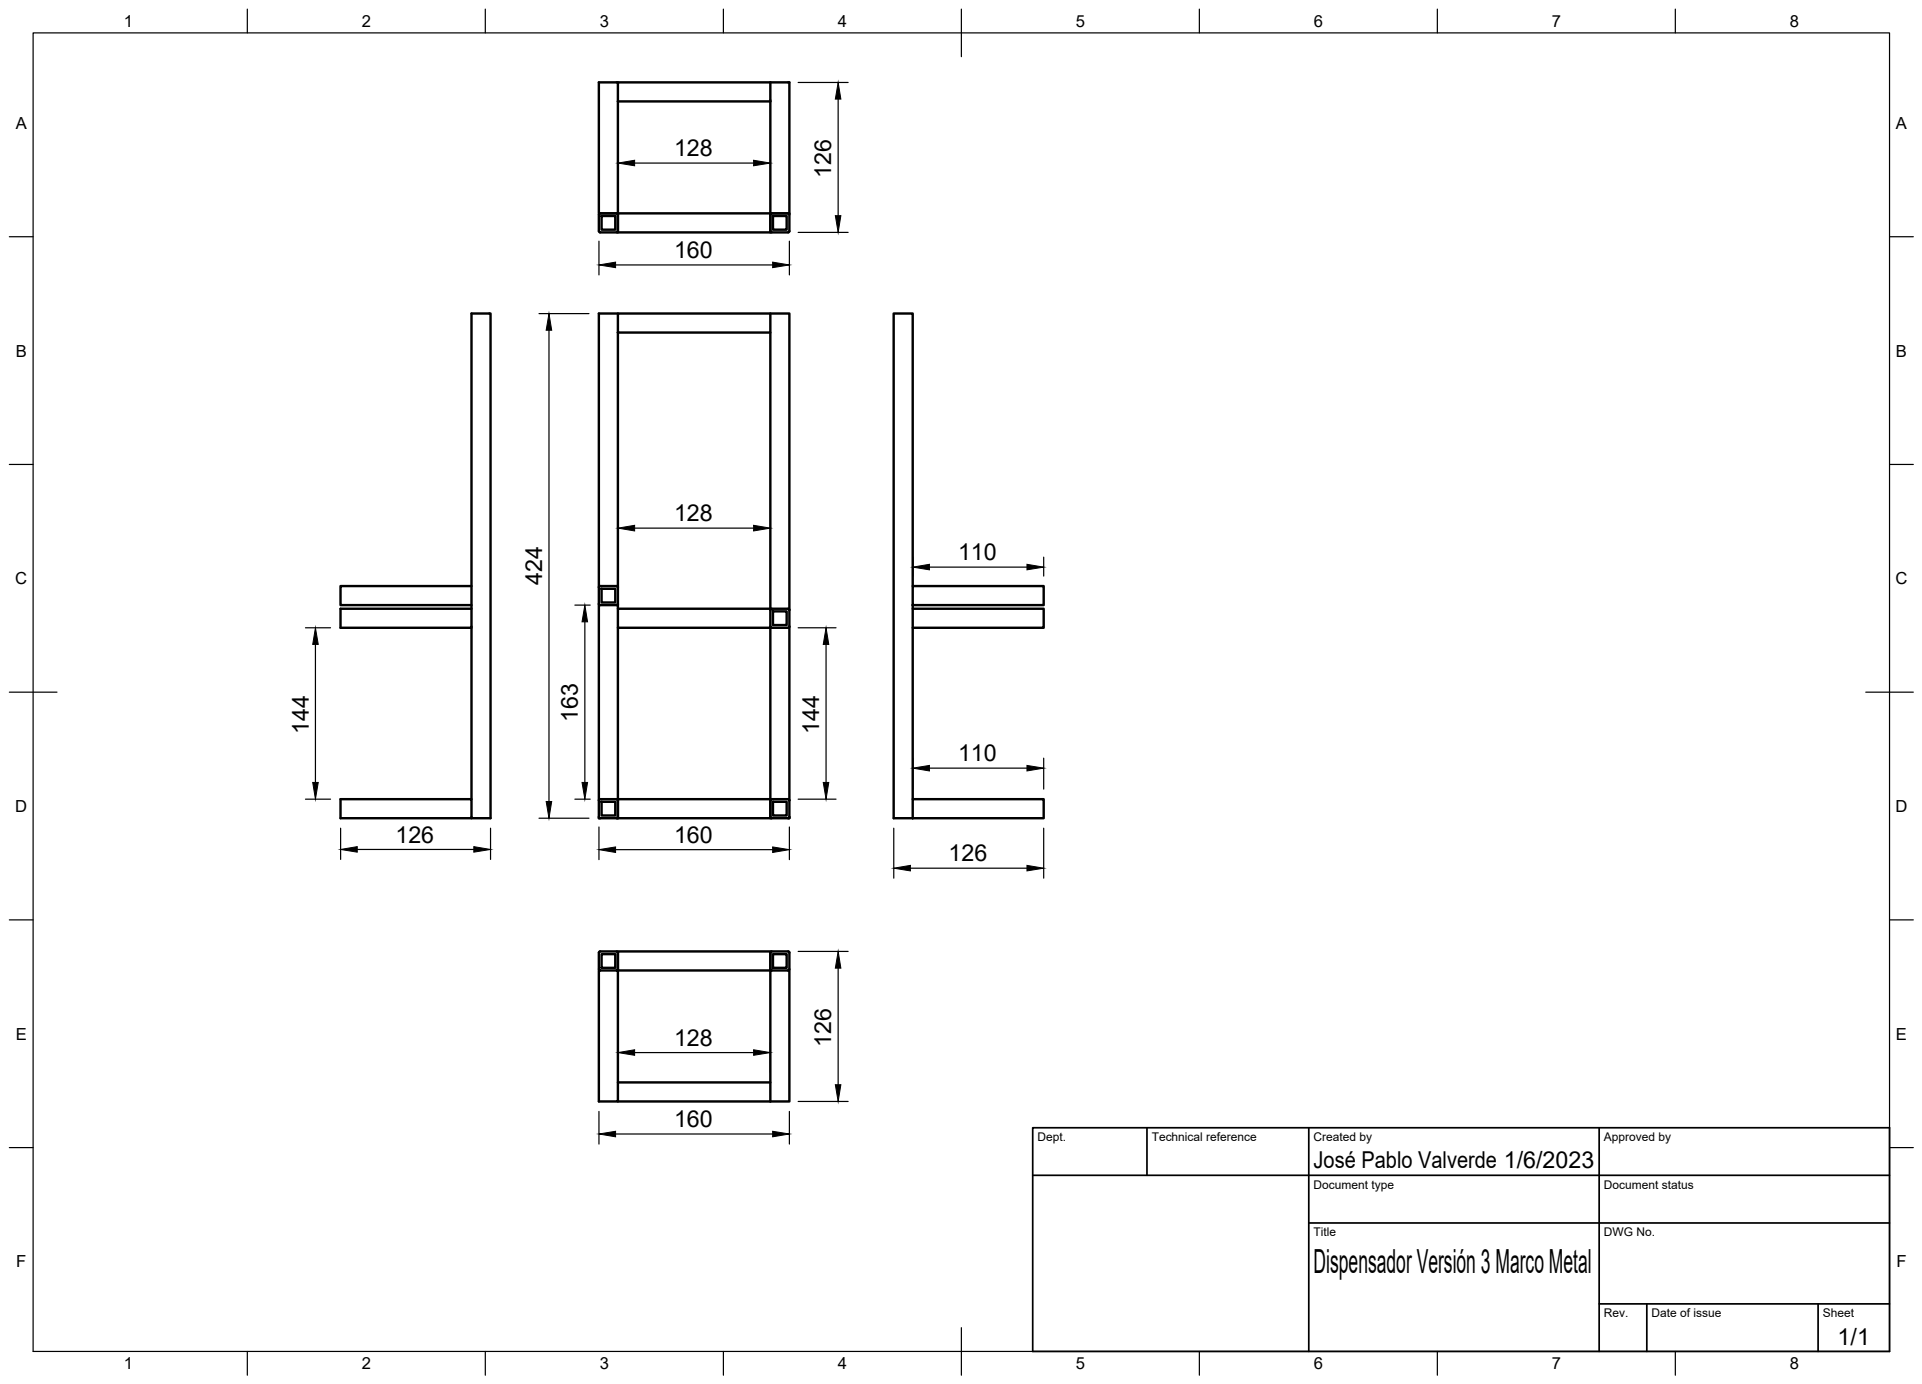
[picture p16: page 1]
Title; DWG No.; Rev.; Date of issue; Sheet

Dept. | Technical reference | Created by José Pablo Valverde 1/6/2023 | Approved by

Document type | Document status

Dispensador Versión 3 Marco Metal

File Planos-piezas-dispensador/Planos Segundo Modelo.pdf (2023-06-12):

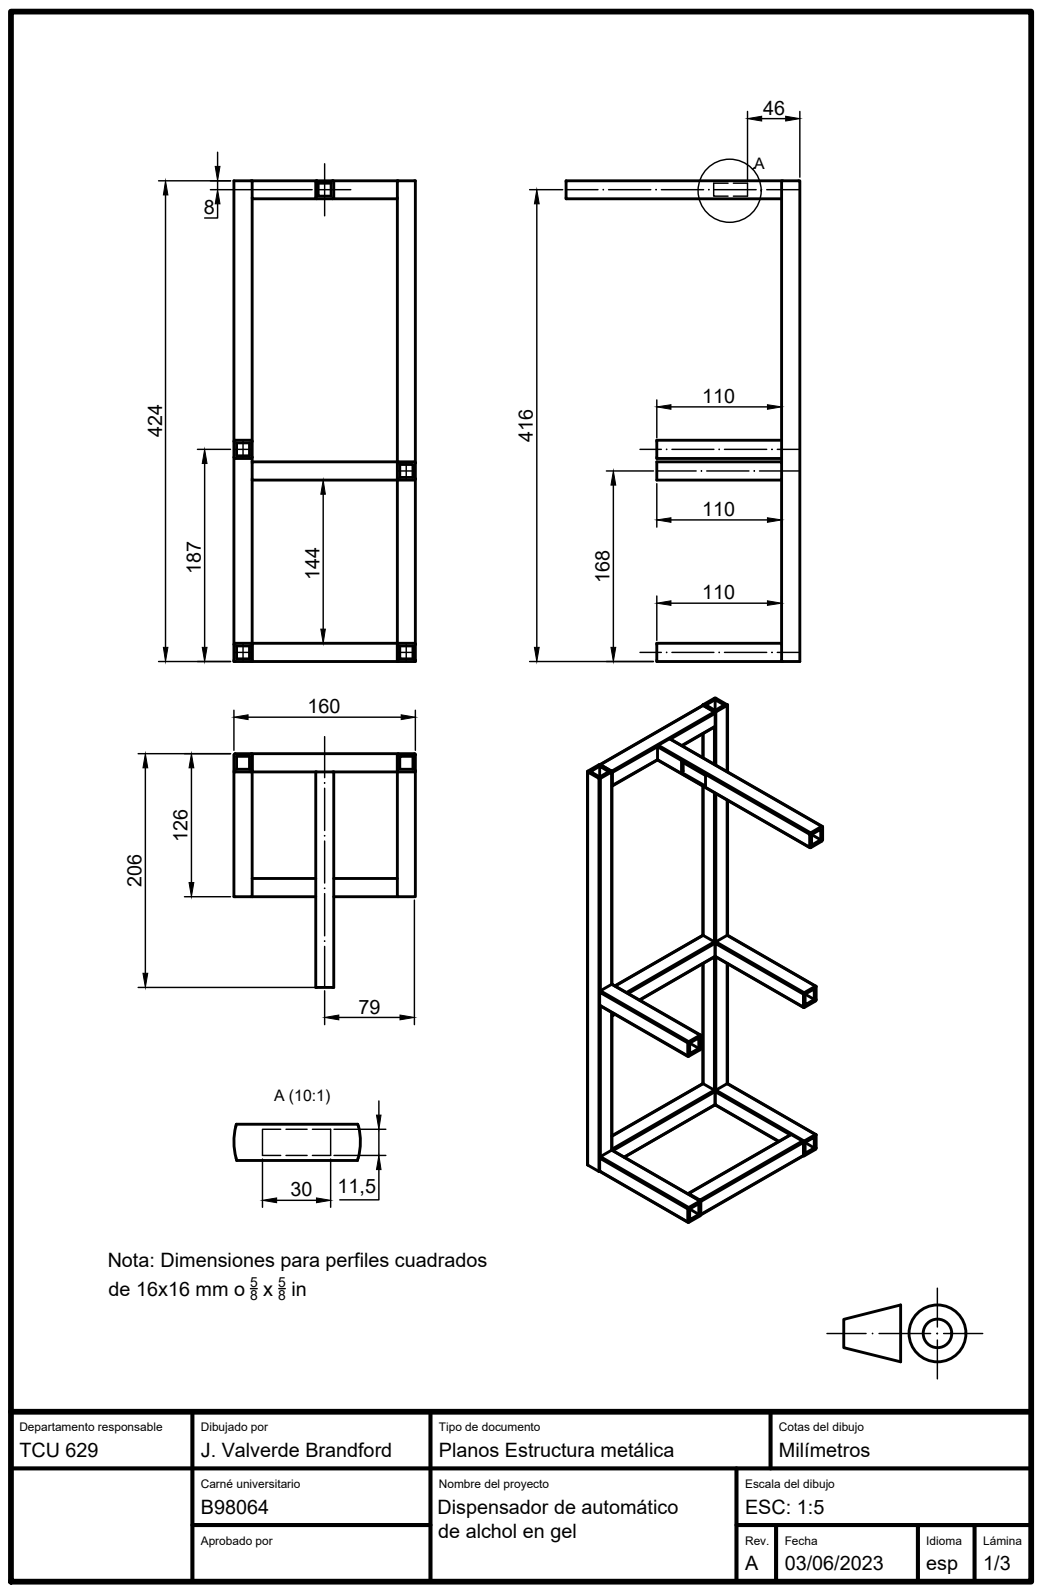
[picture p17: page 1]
79 ¹²⁶ ¹⁸⁷; Departamento responsable; Dibujado por; Carné universitario; Aprobado por; Rev.; Fecha; Idioma esp; J. Valverde Brandford; TCU 629; Planos Estructura metálica

Nota: Dimensiones para perfiles cuadrados

Tipo de documento

Cotas del dibujo
Milímetros

Nombre del proyecto
Dispensador de automático
de alchol en gel

Escala del dibujo
Lámina ESC:

D:\Documents\LogoINGMECÁNICA.png

## Escala 1:5

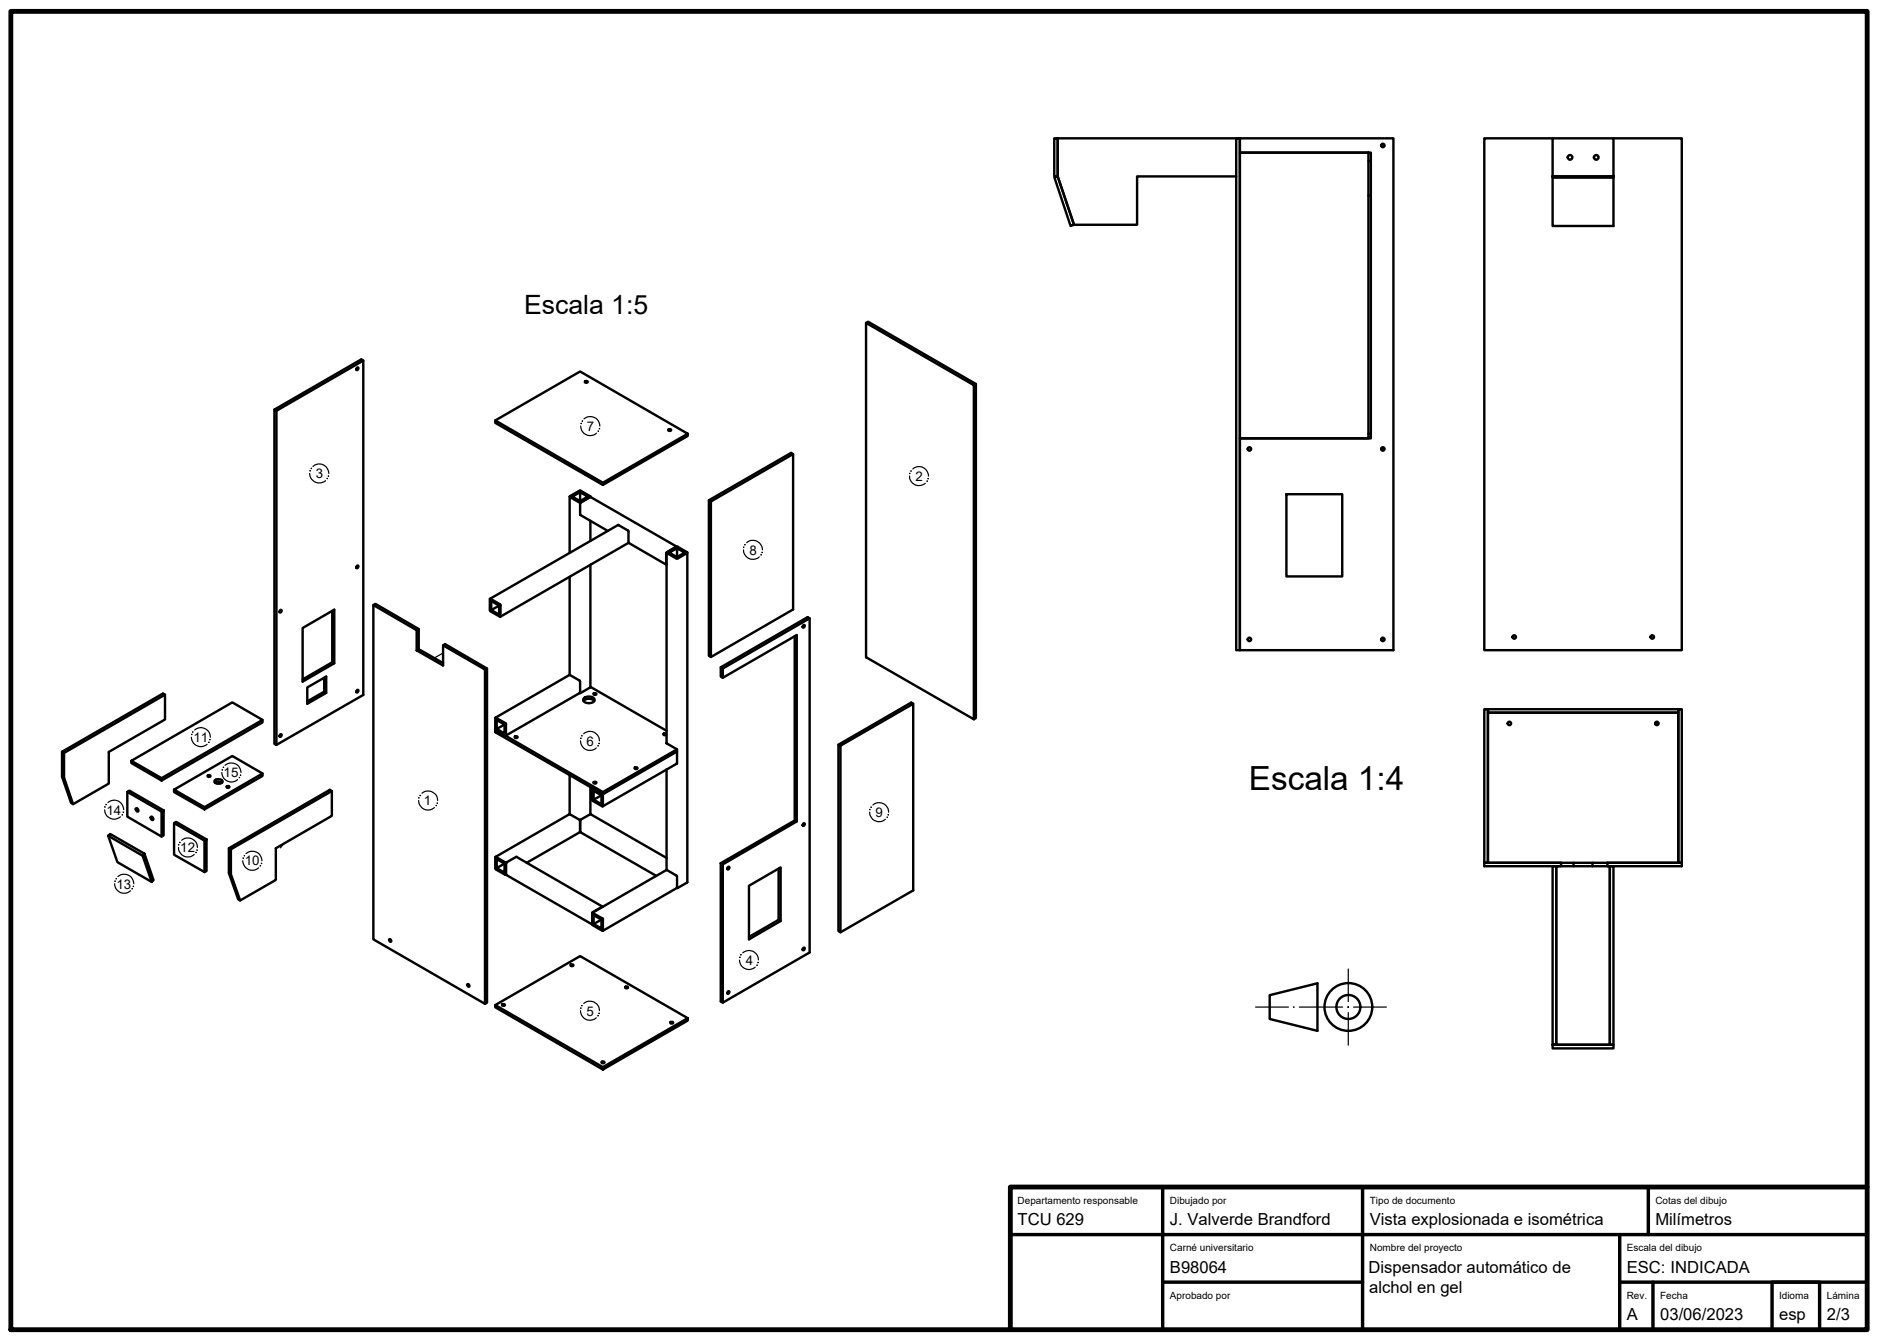
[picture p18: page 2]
Escala 1:4; Departamento responsable; Dibujado por; Carné universitario; J. Valverde Brandford; TCU 629; Vista explosionada e isométrica

Tipo de documento

Cotas del dibujo
Milímetros

Nombre del proyecto
Dispensador automático de
alchol en gel

Escala del dibujo
INDICADA

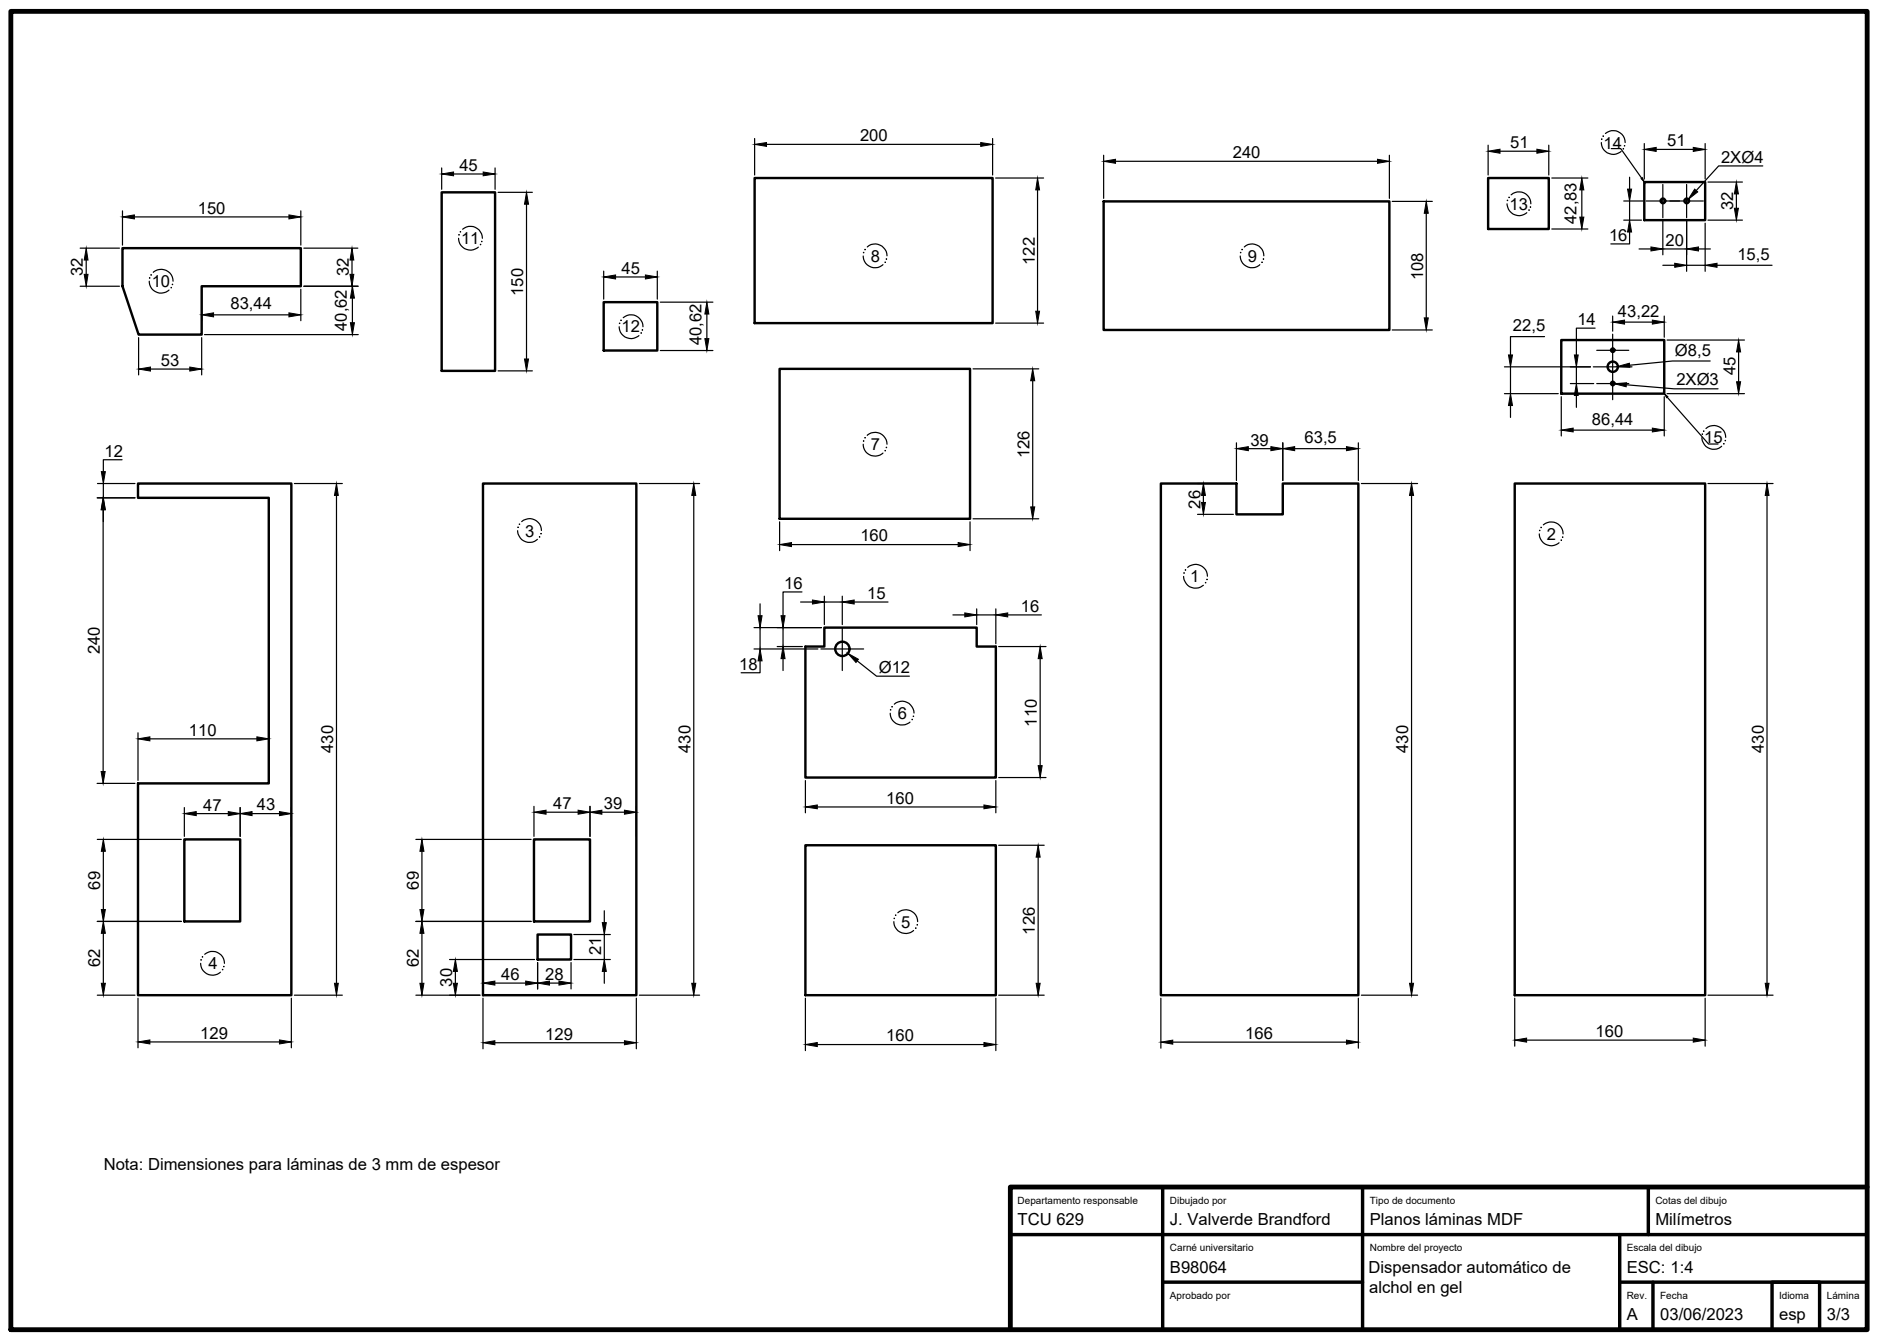
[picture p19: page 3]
160 ⁴³⁰; 110 ²⁴⁰; Departamento responsable; Dibujado por; Carné universitario; J. Valverde Brandford; TCU 629; Planos láminas MDF

Nota: Dimensiones para láminas de 3 mm de espesor

Tipo de documento

Cotas del dibujo
Milímetros

Nombre del proyecto
Dispensador automático de
alchol en gel

Escala del dibujo

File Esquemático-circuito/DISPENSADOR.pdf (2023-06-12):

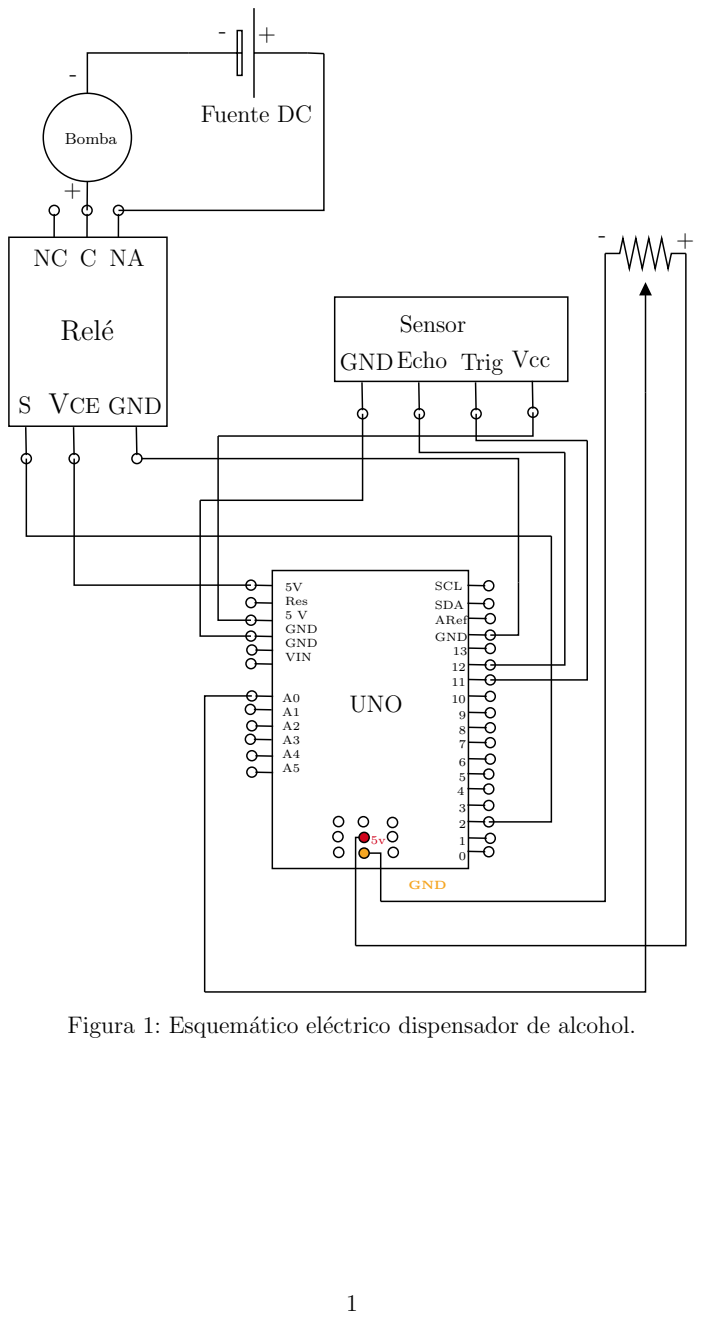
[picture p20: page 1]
UNO; 5V Res 5 V GND GND VIN; SCL; Bomba; S VCE GND; Rel´e; Fuente DC; GND; GNDEcho Trig; Sensor; Vcc; SDA ARef GND 13 12 11 10 9 8 7

Figura 1: Esquem´atico el´ectrico dispensador de alcohol.

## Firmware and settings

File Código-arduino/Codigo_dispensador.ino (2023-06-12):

/**
 * @file Codigo dispensador. 
 *
 * @brief Este el código oficial que se usa para el dispensador alcohol.
 */

// CREACIÓN DE LAS CONSTANTES
const int rele = 2;        ///< Número del pin para el relé que acciona la bomba
int trig = 12;             ///< Número del pin para el pin de disparo (trig) del sensor ultrasónico
int echo = 11;             ///< Número del pin para el pin de eco (echo) del sensor ultrasónico
float distancia;           ///< Distancia de activación del sensor ultrasónico
long duracion;             ///< Duración en la que se mantiene activo el sensor ultrasónico
int pot;                   ///< Variable para leer el valor del potenciómetro (0 a 1023)
int cantidad;              ///< Variable para relacionar el valor del potenciómetro con la cantidad de alcohol
int led_rojo = 5;          ///< Número del pin para el LED rojo
int led_verde = 6;         ///< Número del pin para el LED verde
const int buzzer = 9;      ///< Número del pin para el zumbador

void setup() {
  Serial.begin(9600);             // Iniciar el puerto serie
  pinMode(rele, OUTPUT);          // Configurar el pin como salida para el relé
  pinMode(trig, OUTPUT);          // Configurar el pin de disparo (trig) como salida
  pinMode(echo, INPUT);           // Configurar el pin de eco (echo) como entrada
  pinMode(led_rojo, OUTPUT);      // Configurar el pin del LED rojo como salida
  pinMode(led_verde, OUTPUT);     // Configurar el pin del LED verde como salida
  pinMode(buzzer, OUTPUT);        // Configurar el pin del zumbador como salida
}

void loop() {
  // Código para leer el potenciómetro
  pot = analogRead(A0);            // Leer el valor del potenciómetro (va de 0 a 1023)
  cantidad = pot / 10.23;          // Relacionar el valor del potenciómetro con la cantidad de alcohol (de 0 a 100)
  Serial.print("Cantidad es de = "); // Imprimir mensaje sobre la cantidad de alcohol
  Serial.println(cantidad);        // Imprimir la cantidad de alcohol (duración de la bomba en milisegundos)

  // Código para el sensor ultrasónico
  digitalWrite(trig, LOW);        // Apagar el sensor ultrasónico
  delayMicroseconds(2);            // Esperar durante un breve tiempo
  digitalWrite(trig, HIGH);       // Encender el sensor ultrasónico
  delayMicroseconds(10);           // Esperar durante un breve tiempo
  digitalWrite(trig, LOW);        // Apagar el sensor ultrasónico
  duracion = pulseIn(echo, HIGH);  // Obtener la duración del eco del sensor ultrasónico
  distancia = duracion / 57.8;     // Convertir el tiempo en distancia (cm)
  Serial.print(distancia);         // Monitorear la distancia de activación
  Serial.println("cm");            // Monitorear la distancia de activación

  digitalWrite(led_rojo, LOW);
  digitalWrite(led_verde, HIGH);

    // Código para accionar la bomba
  if (distancia <= 12 && distancia > 7) { // Definir el rango de funcionamiento del sensor para la bomba
    delay(500);                       // Demora antes de activar la bomba después de que se active el sensor
    digitalWrite(rele, HIGH);         // Activar la bomba
    digitalWrite(led_verde, LOW);
    digitalWrite(led_rojo, HIGH);
    delay(cantidad);                   // Duración en la que la bomba debe estar activa (define la cantidad de alcohol)
    digitalWrite(rele, LOW);          // Desactivar la bomba

    analogWrite(buzzer, 5000);
    delay(3000);                       // Demora antes de que la bomba pueda funcionar nuevamente si se utiliza continuamente
    analogWrite(buzzer, 0);
  }

  //delay(100); // Este delay es para reducir la cantidad de lecturas consecutivas del sensor
}

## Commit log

2023-06-12 Versiones de codigo
2023-06-12 crear la carpeta 'Diseño 3D'
2023-06-12 Actualizando archivos planos
    [Base Sensor Hueco 2.0 v6 v7 v2.f3d, BoquillaConica v2.f3d, Manilla v2.f3d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]
